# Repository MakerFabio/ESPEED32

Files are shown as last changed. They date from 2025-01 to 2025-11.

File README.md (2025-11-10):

# SlotEsp32
WARNING: the magnetic sensor TLE493D-P3B6 A0 is the version 3 silicon available on Digikey or mouser. Please note the older version (P2) has issues , some other guys have been able to make it working, but I was not.  Please note, the last part (A0) of the part number is related to the address, if you purchase TLE493D-P3B6 A0 it will have 0x5D, A1 it will have 0x13, and so on, please double check the part number you ordered, and the datasheet for the proper address (I think we are using the 7 bit address )

Cutting edge Slot car controller that has an ESP32 at its heart.
How to built it video:
https://www.youtube.com/watch?v=JtMKeiguHKI
ThumbV2

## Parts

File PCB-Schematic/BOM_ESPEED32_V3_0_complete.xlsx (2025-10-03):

Comment | Designator | Footprint
Comment | Designator | Footprint | JLCPCB Part #（optional） | JLC BASIC/EXTENDED | Mounting Option | Quantity | Description
NO_POP_Mill-Max 2501-2-00-80-00-00-07-0 | 5V | TEST POINT MILL-MAX 2501-2-00-80-00-00-07-0 |  |  | DO NOT MOUNT | 1 | testpad 1mm diameter
BUZ9032SMD | BUZ | BUZ9032_SMD |  | BuySeparately |  | 1 | Header, 2-Pin
100nF | C1, C6, C8, C9, C10, C11, C12 | C0603 | C28233 | BASIC |  | 7 | CAP / CERA / 100nF / 25V / 10% / X8R (EIA) / -55°C to 150°C / 0603(1608) / SMD / -
10nF 50V 0603 | C2, C4, C7, C13, C14 | C0603 | C57112 | BASIC |  | 5 | CAPACITOR, European symbol
22uF | C3, C15, C16 | CAPC3225X270N | C13585 | BASIC |  | 3 | CAP / CERA / 22uF / 25V / 20% / X5R (EIA) / -55°C to 85°C / 1210(3225) / SMD / -
1uF | C5 | CAPC1608X87N-1 | C15849 | BASIC |  | 1 | CAP / CERA / 1uF / 25V / 20% / X5R (EIA) / -55°C to 85°C / 0603(1608) / SMD / -
5016 | CAP-, CAP+, GND, VIN+, WIPER | CON-SMD-TP-5016 |  |  | DO NOT MOUNT | 5 | Test Point, Compact, Surface Mount, Finish- Silver Plate
RF05VYM2SFH | D2 | DIO-SMD-RF05VYM2SFH | C509964 |  |  | 1 | Super Fast Recovery Diode
ZENER 10V(MM3Z10VT1G) | DZ3 | SOD323 | C39057 |  |  | 1 | Zener 10V MM3Z10VST1G
PEC11L-4120K-S0020 | ENC1 | SW-THT-PEC11L-4XXXK-SXXXX |  |  | DO NOT MOUNT | 1 | 11 mm Low Profile Encoder
HTSW-103-07-G-S | EXT_MOT, T_POT | CON-THT-2.54-3-1-8.38 |  |  |  | 2 | Through hole .025 SQ Post Header, 2.54mm pitch, 3 pin, vertical, single row
IFX7805ABTF | G1 | TO228P998X235-3N-2-V | C897464 | Extended |  | 1 | Three Terminal 1.0A Positive Voltage Regulator
OLED128x64 MDOB128064V2V-YI | OLED1 | OLED 128X64 1.3" |  |  |  | 1 | Header, 4-Pin
2N7002WT1G | Q1 | SOT65P220X100-3N | C232391 | Extended |  | 1 | Insulated-Gate Field-Effect Transistor (IGFET), N-Channel, Enhancement, Body Diode, Resistor Gate, ESD Diode Gate/Source, Pin 1 Gate, 2 Source, 3 Drain, 3 Pins
IPD90P03P4L-04 | Q2 | TO228P998X235-3N-2-V |  |  |  | 1 | OptiMOS - P2 Power-Transistor, P-channel-Enhancement mode, VDS -30V
0R | R1, R16, R18, R19 | R0603 | C21189 | DOUBLE CHECK |  | 4 | General Purpose Chip Resistor
10k | R2, R9, R10, R11, R12, R13, R15 | R0603 | C25804 | BASIC |  | 7 | RES / STD / 10k / 100mW / 5% / 100ppm/K / -55°C to 155°C / 0603(1608) / SMD / -
2.2k | R3, R6, R7, R8, R14, R20, R21, R22, R23, R24 | R0603 | C4190 | BASIC |  | 10 | RES / STD / 2.2k / 100mW / 1% / 100ppm/K / -55°C to 155°C / 0603(1608) / SMD / -
N.M. 0R | R4, R5 | R0603 |  |  |  | 2 | General Purpose Chip Resistor
PTS645SM43SMTR92 LFS | S1 | SW-SMD-PTS645SK43SMTR92 | C285473 |  |  | 1 | Tact Switches, Variety of Actuator Lengths
HTSW-104-07-G-S | SPARE | HDRV4W64P254_1X4_1016X248X838B |  |  | DO NOT MOUNT | 1 | Through hole .025 SQ Post Header, Hi-Temp Strip, 2.54mm pitch, 4 pin, vertical, single row
ESP32-DEVKIT-V1 | U1 | MODULE_ESP32_DEVKIT_V1 |  |  |  | 1 | Dual core, Wi-Fi: 2.4 GHz up to 150 Mbits/s,BLE (Bluetooth Low Energy) and legacy Bluetooth, 32 bits, Up to 240 MHz
BTN9960LV | U2 | IFX-PG-HSOF-7-1-V |  |  |  | 1 | MOTIX Single Half-Bridge with Integrated Driver IC
TLE493D-W2B6 A3 | U3 | SOP95P280X110-6N-V |  |  |  | 1 | Low Power 3D Hall Sensor with I2C Interface and Wake Up Function, Temp Range(-40 to 125°C)
LEGENDA:(colour code)
Not mounted but Nice to havefrom digik | Extended of Basic | NOT needed /not mounted |  |  |  | I will mount later by myself

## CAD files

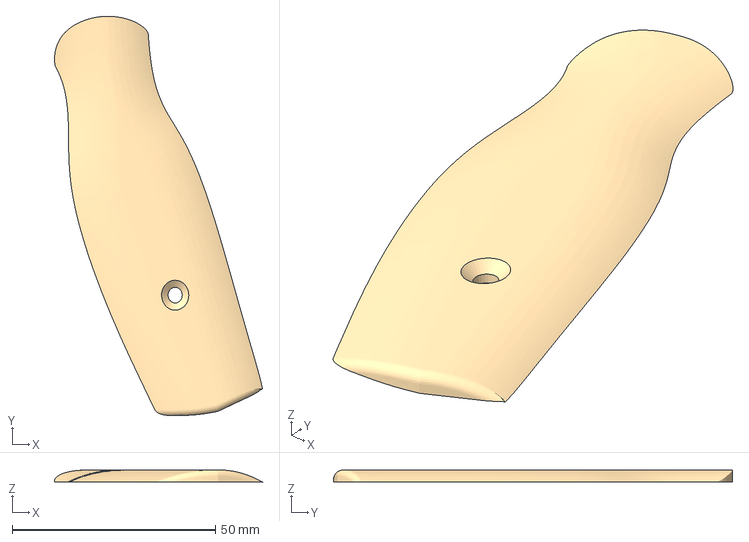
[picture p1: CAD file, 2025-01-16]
Mechanical/3DprintFiles/RoundingTopV47.3mf
51.1 x 98.2 x 3.00 mm

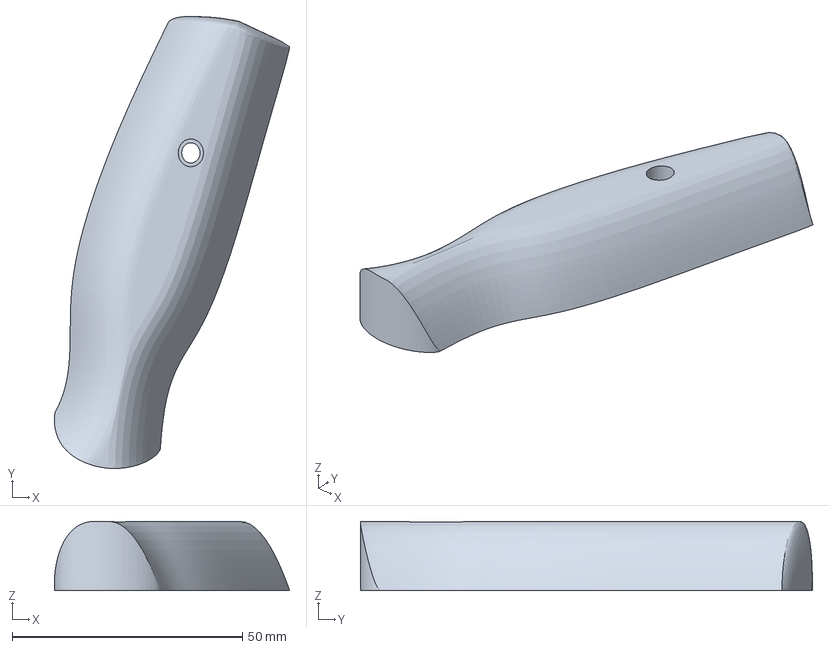
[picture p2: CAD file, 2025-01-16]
Mechanical/3DprintFiles/RoundingBotAddia_15mmV47.3mf
51.1 x 98.2 x 15.0 mm

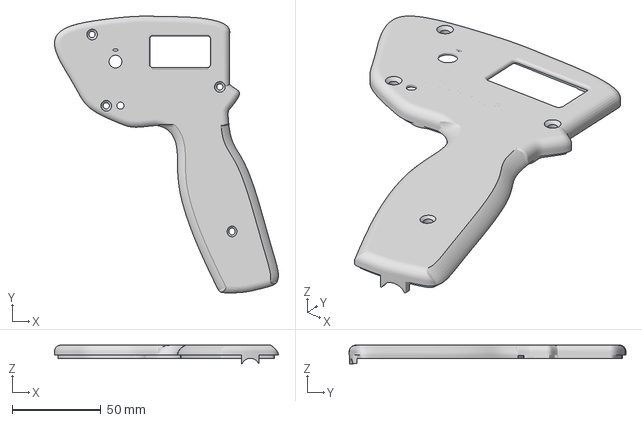
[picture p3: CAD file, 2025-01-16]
Mechanical/3DprintFiles/HandleTopV29.3mf
126.1 x 155.8 x 10.6 mm

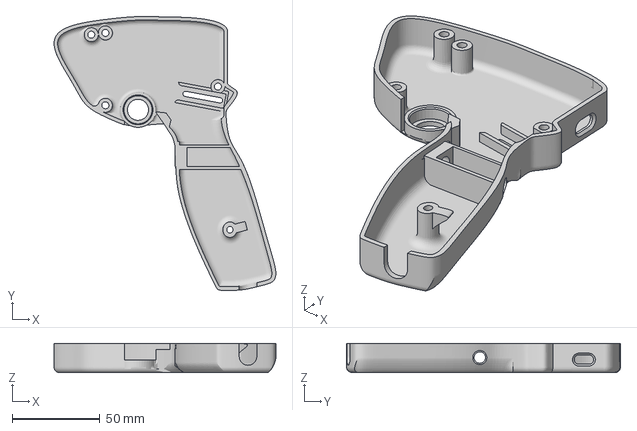
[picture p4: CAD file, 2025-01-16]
Mechanical/3DprintFiles/HandleBotV29.3mf
126.1 x 155.8 x 16.5 mm

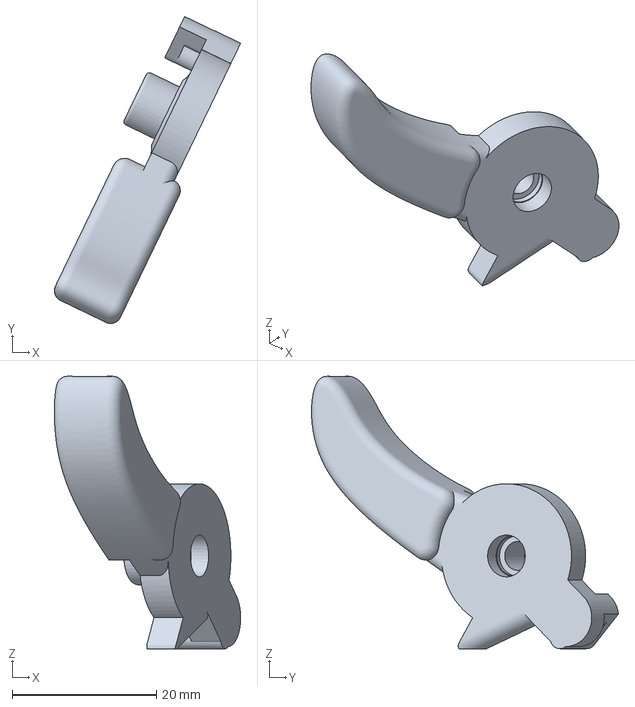
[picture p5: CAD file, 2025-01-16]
Mechanical/3DprintFiles/TrigVeryThick10mm.3mf
25.8 x 42.5 x 37.8 mm

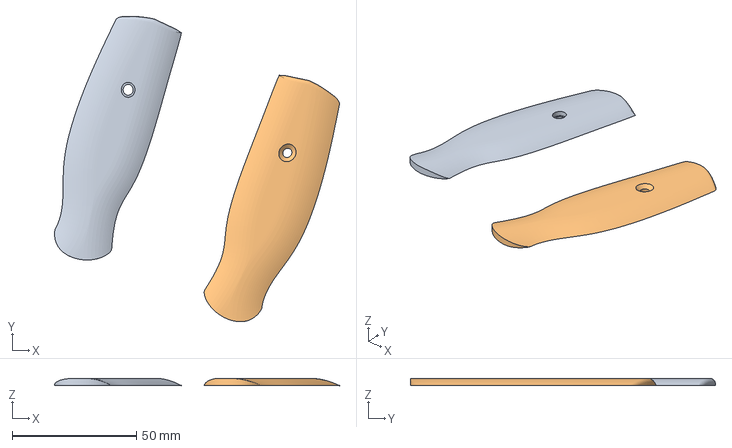
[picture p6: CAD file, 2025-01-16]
Mechanical/3DprintFiles/Rounding2sides.3mf
114.8 x 123.0 x 3.00 mm
RoundingBot
RoundingTop

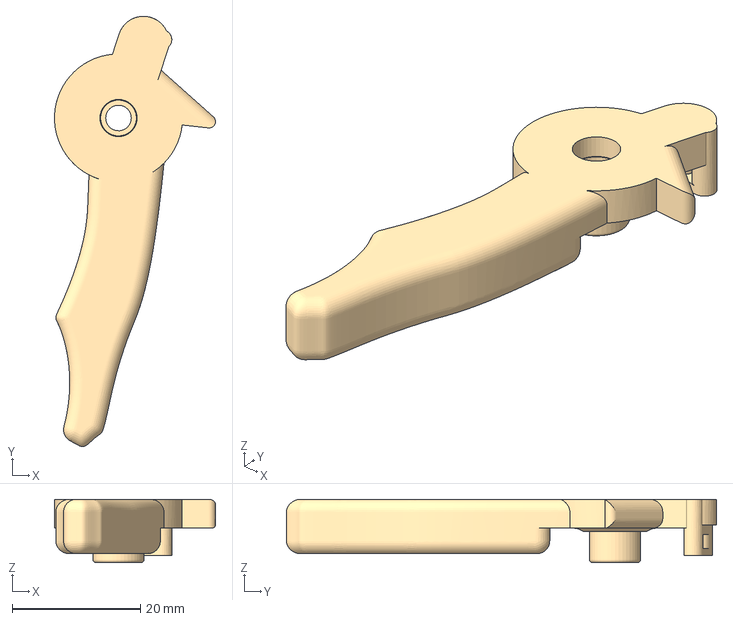
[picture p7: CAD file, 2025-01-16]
Mechanical/3DprintFiles/TrigLongV33.3mf
25.1 x 67.2 x 9.90 mm

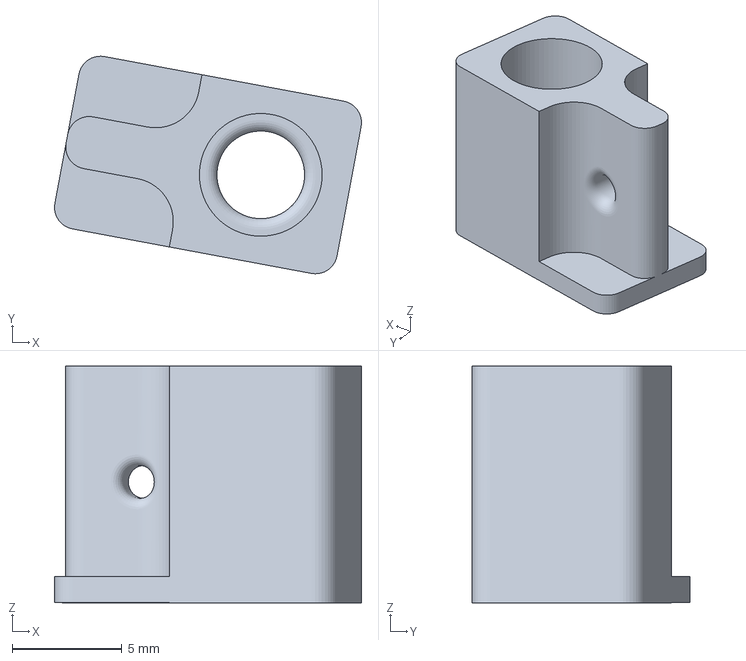
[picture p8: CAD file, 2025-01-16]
Mechanical/3DprintFiles/Slide.3mf
14.0 x 9.93 x 10.8 mm

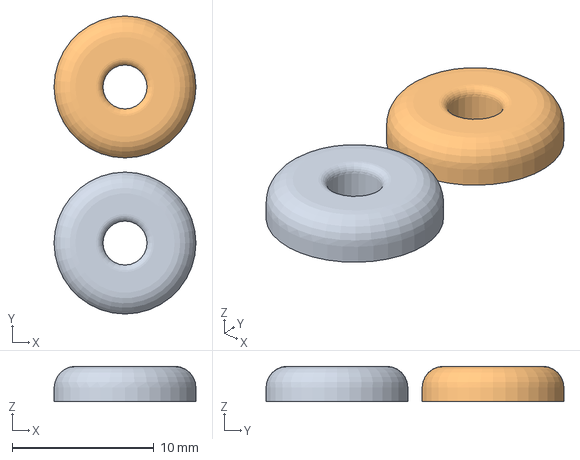
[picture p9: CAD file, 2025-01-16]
Mechanical/3DprintFiles/WasherOnly.3mf
10.0 x 21.0 x 2.50 mm
Washer x 2

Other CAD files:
Mechanical/3DprintFiles/RoundingBotv47.3mf

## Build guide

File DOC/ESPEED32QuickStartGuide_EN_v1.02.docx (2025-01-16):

# ESPEED32 Slot Car Electronic Speed Controller

Quick Start Guide

EN

## Introduction

The ESPEED32 is a powerful Slot Car Electronic Speed Controller based on the 32-bit ESP32 microcontroller.

## Calibration

The calibration of the trigger travel must be performed every time the trigger travel is changed, or the firmware is updated. To perform the trigger calibration, keep pressed the rotary selector while powering the ESPEED32, until the calibration screen appears. Fully press and release the trigger a few times, then press the rotary selector once. To verify a proper calibration, check if the throttle is showing 0% when the trigger is fully released, and 100% when the trigger is fully pressed.

## Navigating the screen

Rotate the rotary selector to scroll the settings in the main menu: the selected setting is highlighted. Press the selector once to change the value of the selected setting: the value is now highlighted. Rotate the selector to change the value of the selected setting, then press the selector again to confirm the value.

## Settings

SENSI – Sensitivity: Indicates the power provided to the motor when the minimum detectable pressure is applied to the trigger. The sensitivity should be at least sufficient for the car to start moving. If the track is “fast” or the car is “heavy”, then a higher sensitivity can be chosen. SENSI measurement unit is percent [%] and ranges from 0% to 90%.

BRAKE – Brake level: Indicates how strong the motor will brake when the trigger is completely released. In order to perform the brake, the motor is shorted with a PWM whose duty cycle is equal to the value of BRAKE. BRAKE measurement unit is percent [%] and ranges from 0% to 100% (100% means max brake is applied).

ANTIS – Anti-spin: Anti-spin (traction control) is used to provide a smooth power ramp to the motor, even if the trigger is pressed abruptly. ANTIS is expressed in milliseconds [ms]. It indicates how much time it takes for the motor to reach 100% power with the trigger fully pressed. If ANTIS is set to 150 ms and the trigger is pressed instantaneously, then the motor will receive a power ramp that will take 150ms to reach the max power. The higher the number the softer is the power ramp applied. ANTIS possible value ranges from 0 ms to 250 ms.

Typical ANTIS value: 130 ms for 1/32 cars; 0 ms for 1/24 cars

CURVE – Trigger-to-motor power curve: the CURVE parameter allows to customize the mapping of the trigger position to the motor power output. A default value of 50% corresponds to a linear curve. If CURVE is <50% the response of the trigger will be softer at the beginning of the travel and more aggressive at the end; vice versa if CURVE is >50%. Ranges from 10% to 90%.

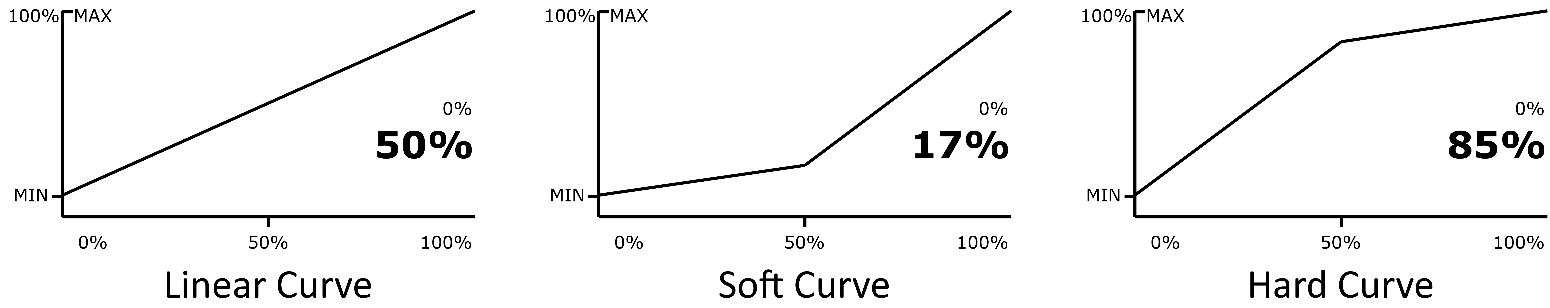
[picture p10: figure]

Figure 1 CURVE setting examples.

PWM_F – motor PWM frequency: the frequency of the PWM (Pulse Width Modulation) used to control the motor. A higher frequency produces a softer response, especially at low trigger positions; a lower frequency produces higher torque with minimum throttle and more linear response. PWM_F measurements unit is Kilohertz [kHz] and ranges from 0.2kHz to 5.0kHz

Table 1 Settings overview

Setting | Recommended value | Range | | Unit
| | Min. | Max.
SENSI | 10 | 0 | 90 | %
BRAKE | 95 | 0 | 100 | %
ANTIS | 150 for 1/32 cars 0 for 1/24 cars | 0 | 255 | ms
CURVE | 50 | 10 | 90 | %
DRAGB | 100 | 0 | 100 | %
PWM_F | 3 | 0.2 | 5.0 | kHz

## Electrical Specifications - recommended operating condition

Setting | Symbol | Value | | | Unit
| | Min. | Typ. | Max.
Power supply voltage | VIN+ | 6.0 | 12 | 18 | V
Motor Current | I_(VDD) | 35 | 47 | 60 | mA
Startup Time | t_(startUp) | - | 150 | - | ms

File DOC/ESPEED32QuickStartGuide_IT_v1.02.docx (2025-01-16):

# ESPEED32 Quick Start Guide

Guida rapida

IT

## Introduzione

L’ ESPEED32 è un pulsante professionale per slot car basato sul microcontrollore ESP32 a 32 bit.

## Calibrazione

La calibrazione del grilletto deve essere eseguita ogni volta che si modifica la corsa del grilletto o si aggiorna il firmware. Per eseguire la calibrazione del grilletto, mantenere premuto il selettore rotativo mentre si alimenta l’ ESPEED32, finché non appare la schermata di calibrazione. A questo punto rilasciate il pulsante sul selettore rotativo. La calibrazione consiste nel premere e rilasciare completamente il grilletto 2-3 volte, quindi premere nuovamente volta il selettore rotativo per uscire e salvare la calibrazione. Per verificare che la calibrazione sia corretta, controllare se l’indicatore dell’acceleratore mostra 0% quando il grilletto è completamente rilasciato e 100% quando il grilletto è completamente premuto.

## Navigazione sullo schermo

Ruotare il selettore rotativo per scorrere le impostazioni nel menu principale: l'impostazione selezionata è evidenziata. Premere una volta il selettore per modificare il valore dell'impostazione selezionata: il valore è ora evidenziato. Ruotare il selettore per modificare il valore dell'impostazione selezionata, quindi premere nuovamente il selettore per confermare il valore.

## Impostazioni

SENSI – Sensibilità: Indica la potenza minima fornita al motore. E’ la potenza che viene applicata al motore alla minima pressione rilevabile al grilletto. La sensibilità dovrebbe essere almeno sufficiente per far partire l'auto. Se il percorso è "veloce" o l'auto è poco sensibile, è possibile scegliere una sensibilità (SENSI) maggiore, anche il 50% per esempio. L'unità di misura SENSI è percentuale [%] e varia da 0% a 90%.

BRAKE – Livello freno: Indica la potenza di frenata del motore quando il grilletto viene completamente rilasciato. Per eseguire la frenata, il motore viene messo in cortocircuito con un PWM il cui ciclo di lavoro è uguale al valore di BRAKE. L'unità di misura BRAKE è percentuale [%] e varia da 0% a 100% (100% significa che è applicata la massima frenata).

ANTIS – Antispin: Antispin (controllo della trazione)

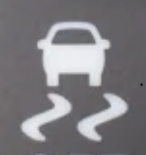
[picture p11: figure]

L’antispin viene utilizzato per fornire una rampa graduale di potenza al motore, anche se il grilletto viene premuto bruscamente. Questo previene lo slittamento della macchina. ANTIS è espresso in millisecondi [ms]. Indica quanto tempo impiega il motore a per andare da 0% al 100% di potenza quando il grilletto viene premulto bruscamente.Ad esempio, ANTIS= 150ms e il grilletto viene premuto istantaneamente, il motore riceverà una rampa di potenza che impiegherà 150 ms per raggiungere la potenza massima. Più alto è il numero sul parametero ANITS, più morbida è la rampa di potenza applicata. I valori possibili di ANTIS vanno da 0 ms a 250 ms. Valore ANTIS tipico: 130 ms per auto 1/32; 0 ms per auto 1/24


CURVE –Curva posizione trigger/potenza motore. il parametro CURVE consente di personalizzare la mappatura della posizione del trigger in base alla potenza in uscita dal motore. Un valore predefinito del 50% corrisponde a una curva lineare. Se CURVE è <50% la risposta del trigger sarà più morbida all'inizio della corsa e più aggressiva alla fine; viceversa seCURVE è >50%. Varia dal 10% al 90%.

PWM_F – frequenza PWM del motore: la frequenza del PWM (Pulse Width Modulation) utilizzato per controllare il motore. Una frequenza più alta produce una risposta più morbida, specialmente a basse posizioni di trigger; una frequenza più bassa produce una coppia più alta con accelerazione minima e una risposta più lineare. L'unità di misura PWM_F è Kilohertz [kHz] e varia da 0,2kHz a 5,0kHz

Parametro | Valore consigliato | Range | Unità di misura
SENSI | 10% | 0% - 90% | Percentuale [%]
BRAKE | 90% | 0% - 100% | Percentuale [%]
ANTIS | 130 ms per 1/32, 0 ms per 1/24 | 0 - 250 ms | Millisecondi [ms]
CURVE | 50% | 10% - 90% | Percentuale [%]
DRAGB | 100% | 0% - 100% | Percentuale [%]
PWM_F | 3 kHz | 0,2 - 5,0kHz | Chilohertz [kHz]

## Electrical Characteristics (recommended operating condition)

Setting | Symbol | Value | | | Unit
| | Min. | Typ. | Max.
Power supply voltage | VIN+ | 6.0 | 12 | 18 | V
Motor Current | I_(VDD) | 35 | 47 | 60 | mA
Startup Time | t_(startUp) | - | 150 | - | ms

ESPEED32|Quick Start Guide

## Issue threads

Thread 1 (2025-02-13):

parts

FTSSMike, 2025-02-13:
has anyone found the Infineon part out there somewhere or is there anther part that can be used. Also looks like one part is discontinued does anyone have a part number to replace it?  thank you

TurboMikeFTS, 2025-02-21:
I found everything but the hall sensor if anyone sees one please post up

Hcbo1967, 2025-02-22:
I'd like to help improve this. Can you send me all the files including Gerber files of the PCB?
Hamilton
thank you

fehcbo@yahoo.com

TurboMikeFTS, 2025-02-22:
I will when i get to my office

jeppojeps, 2025-03-09:
@MakerFabio would this work

726-TLE493DW2B6A3HTS
https://www.mouser.es/ProductDetail/Infineon-Technologies/TLE493DW2B6A3HTSA1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

TurboMikeFTS, 2025-03-09:
I have a couple on order to try, read the comments on you tube someone got it to work but some code was changed

jeppojeps, 2025-03-22:
I believe finally it's available

https://www.digikey.es/en/products/detail/infineon-technologies/TLE493DP3B6A0HTSA1/25902161

@MakerFabio is the correct one no?

MakerFabio, 2025-03-23:
yes, it is finally available
the part you pointed is correct

FTSSMike, 2025-04-07:
The correct hall sensor just showed up in one of the online stores  https://www.rutronik24.com/product/infineon/tle493dp3b6a0htsa1/24620689.html they show 150 units

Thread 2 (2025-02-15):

polarity change

rufusms, 2025-02-15:
Hello, I found this controller, which I think is fantastic and I started to build it based on the schematics and using a perfboard, I found another half bridge, BTS7960, which is similar and I assembled the circuit, the controller I used is an old NINCO, transformed to work as a potentiometer and I added a declaration in the program, so that it works, the problem I find now is that my track uses the positive instead of the negative , then it works off-piste but not on it.

rufusms, 2025-02-21:
Hello again, I have finally finished building this controller, to use it I had to change the polarity of the track, in general it works very well but I observe that when I put curves with a lower value than 80%, the voltage value does not reach 100%, from 68% it becomes very unstable, I have verified that the noise level at the signal input is very low, of the order of 2% at most, and the stability of the signal is 100%, I thought that since my sensor input is resistive instead of magnetic, it would have more noise and instability but that is not the case, perhaps it is that the acquisition is through an analog input instead of I2C.

TurboMikeFTS, 2025-02-21:
That should be fixable. I’m waiting on some parts and I’ll finish a couple.

Hcbo1967, 2025-02-22:
I'd like to help improve this. Can you send me all the files including Gerber files of the PCB?
Hamilton
thank you

fehcbo@yahoo.com

Hcbo1967, 2025-02-28:
> Olá, encontrei este controlador, que acho fantástico e comecei a montá-lo com base nos esquemas e usando uma perfboard, encontrei outra meia ponte, BTS7960, que é semelhante e montei o circuito, o controlador que usei é um NINCO antigo, transformado para funcionar como um potenciômetro e adicionei uma declaração no programa, para que funcione, o problema que encontro agora é que minha pista usa o positivo em vez do negativo, então funciona fora de pista, mas não nela.

> Olá, encontrei este controlador, que acho fantástico e comecei a montá-lo com base nos esquemas e usando uma perfboard, encontrei outra meia ponte, BTS7960, que é semelhante e montei o circuito, o controlador que usei é um NINCO antigo, transformado para funcionar como um potenciômetro e adicionei uma declaração no programa, para que funcione, o problema que encontro agora é que minha pista usa o positivo em vez do negativo, então funciona fora de pista,

> Olá novamente, finalmente terminei de construir este controlador, para usá-lo tive que mudar a polaridade da trilha, em geral funciona muito bem, mas observo que quando coloco curvas com valor menor que 80%, o valor da tensão não chega a 100%, a partir de 68% fica muito instável, verifiquei que o nível de ruído na entrada do sinal é muito baixo, da ordem de 2% no máximo, e a estabilidade do sinal é de 100%, pensei que como minha entrada de sensor é resistiva em vez de magnética, teria mais ruído e instabilidade, mas não é o caso, talvez seja que a aquisição seja por uma entrada analógica em vez de I2C.

I'm interested in making changes and sharing them here with other users. Can you send me the complete file with all the files for my e-mail?
fehcbo@yahoo.com

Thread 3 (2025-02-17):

BOM missing from repository

one4worldpeace, 2025-02-17:
the Bill of materials was in the file list
and then was replaced with what looked like a record of expenses
and is now not to be found.

the loading screen says “press button” is this referring to the small red button ommitted in your video?

TurboMikeFTS, 2025-02-18:
I can send you my download, send your email

Hcbo1967, 2025-02-22:
I'd like to help improve this. Can you send me all the files including Gerber files of the PCB?
Hamilton
thank you

fehcbo@yahoo.com

TurboMikeFTS, 2025-02-22:
i will send it monday i have the complete zip at my office

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

Hcbo1967, 2025-02-23:
ok
Thanks

one4worldpeace, 2025-02-23:
***@***.*** thank you kindly

On Tue, Feb 18, 2025 at 12:22 PM TurboMikeFTS ***@***.***>
wrote:

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

m4n-u, 2025-08-31:
hell my friend do u have a link to get gerber  file? and  parts list?, thanks

m4n-u, 2025-08-31:
> I can send you my download, send your email

Hello friend how are you, i ve been trying to get all the files to make the controller for my own but i cant find BOM, Gerber, part list, etc, i just read that maybe u have the files, it is posible that you share with me? thanks  manuel.galvez.@live.com

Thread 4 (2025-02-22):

software wont verify

TurboMikeFTS, 2025-02-22:
did anyone get the software to compile properly? I am trying to program the esp32

Hcbo1967, 2025-02-23:
Have you the files Gerber of PCB?
I can help you resolve this.
The Gerber files are currently not available for download.
Please, send me all files fory e-mail.
fehcbo@yahoo.com

Hamilton

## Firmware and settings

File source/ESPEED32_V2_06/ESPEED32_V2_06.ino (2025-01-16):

/*********************************************************************************************************************/
/*------------------------------------------------------Includes-----------------------------------------------------*/
/*********************************************************************************************************************/
#include "slot_ESC.h"

/*********************************************************************************************************************/
/*-------------------------------------------------------Macros------------------------------------------------------*/
/*********************************************************************************************************************/
#define BOOTLOADER_BUILD 1
//#define LOG_LOCAL_LEVEL ESP_LOG_NONE
#define CONFIG_BOOTLOADER_LOG_LEVEL ESP_LOG_NONE

#define SW_MAJOR_VERSION 2
#define SW_MINOR_VERSION 06
#define STORED_VAR_VERSION 4 /* tells which version of stored variable is used for thisproject in case the stored var */
                             /* changes from previous SW release, please increase the STORED_VAR_VERSION by 1         */

/* Last modified: 17/10/2024 */
/*********************************************************************************************************************/
/*-------------------------------------------------Global variables--------------------------------------------------*/
/*********************************************************************************************************************/

//CONFIG_BOOTLOADER_SKIP_VALIDATE_ON_POWER_ON=y not existing
//CONFIG_BOOTLOADER_SKIP_VALIDATE_IN_DEEP_SLEEP


TaskHandle_t Task1;
TaskHandle_t Task2;

static StateMachine_enum g_currState = INIT;
uint16_t debug;

/* Display Backbuffer */
#ifdef USE_BACKBUFFER
static uint8_t ucBackBuffer[1024];
#else
static uint8_t *ucBackBuffer = NULL;
#endif

OBDISP g_obd;       /* Display global instance */

char msgStr[50];    /* Display string global instance */


uint16_t g_carSel;  /* global variable telling whch car model has been selected */

/* Rotary Encoder global instance */
AiEsp32RotaryEncoder g_rotaryEncoder = AiEsp32RotaryEncoder(ENCODER_A_PIN, ENCODER_B_PIN, ENCODER_BUTTON_PIN, ENCODER_VCC_PIN, ENCODER_STEPS);

static uint8_t g_encoderMainSelector = 1;           /* Value of main menu selector (indicates selected item) */
static uint8_t g_encoderSecondarySelector = 0;      /* Value of secondarty selector (indicates selected item's value) */
static uint16_t *g_encoderSelectedValuePtr = NULL;  /* Global instance of pointer to the value selected by the encoder */


/* EEPROM stored values (mainly calibration) global instance */
StoredVar_type g_storedVar;

/* ESC internal variables gloabl instance */
ESC_type g_escVar{
  .outputSpeed_pct = 0,
  .trigger_raw = 0,
  .trigger_norm = 0,
  .encoderPos = 1,
  .Vin_mV = 0,
  .dualCurve = false
};

/* Main menu global instances */
Menu_type g_mainMenu{
  .lines = 3
};

/* Car menu global instances */
Menu_type g_carMenu{
  .lines = 3
};

/* Preferences global instance (for storing NVM data, replace EEPROM library) */
Preferences g_pref;

static uint32_t g_lastEncoderInteraction = 0;  /* tell how much time has passed since last time encoder whas rotated/pressed
                                                  so we can avoid keep printing the display menu and save CPU cycles */

/*********************************************************************************************************************/
/*--------------------------------------------- Function Declaration----------------------------------------*/
/*********************************************************************************************************************/
void IRAM_ATTR readEncoderISR();


/*********************************************************************************************************************/
/*---------------------------------------------Setup Function Implementations----------------------------------------*/
/*********************************************************************************************************************/

/* Setup */
void setup()
{

  /***** Pin and Serial Setup *****/
  HAL_PinSetup();

  /***** HalfBridge & HW Setup *****/
  HalfBridge_SetupFabio();

  /***** create a task that will be executed in the Task1code() and Task2code() funcitons, executed on core 0 and 1 *****/
  /* TASK1: slotESC state machine, managex OLED display and Encoder, low priority task */
  xTaskCreatePinnedToCore(
    Task1code, /* Task function. */
    "Task1",   /* name of task. */
    10000,     /* Stack size of task */
    NULL,      /* parameter of the task */
    1,         /* priority of the task */
    &Task1,    /* Task handle to keep track of created task */
    0);        /* pin task to core 0 */
  /* TASK2: perform trigger reading, trigger conditioning, PWM output */
  xTaskCreatePinnedToCore(
    Task2code, /* Task function. */
    "Task2",   /* name of task. */
    10000,     /* Stack size of task */
    NULL,      /* parameter of the task */
    2,         /* priority of the task */
    &Task2,    /* Task handle to keep track of created task */
    1);        /* pin task to core 1 */
}


/*********************************************************************************************************************/
/*---------------------------------------------MAIN LOOP IN TASKS----------------------------------------------*/
/*********************************************************************************************************************/

/**
 * Task 1: slotESC state machine: manage OLED display and Encoder, low priority task
 */
void Task1code(void *pvParameters) 
{
  for (;;) 
  {
    StateMachine_enum prevState = g_currState;  /* Keep track of the state at the previous loop */
    static uint16_t prevFreqPWM = 0;            /* Keep track if the PWM freq has changed */
    static MenuState_enum menuState = ITEM_SELECTION;   /* State of the Main Menu */
    static uint8_t swMajVer, swMinVer, storedVarVersion;/* SW major version, minor version,  storedVariable version stored in the eeprom */

    g_escVar.Vin_mV = HAL_ReadVoltageDivider(AN_VIN_DIV, RVIFBL, RVIFBH); /* Read VIN */

    if (g_currState != INIT) /* If the user params are already fetched from the EEPROM */
      {
        g_carSel = g_storedVar.selectedCarNumber;    /* Update global variable telling which car model is actually selected */
      }

    /* Task 1 state machine */
    switch (g_currState) {
      case INIT:

        g_pref.begin("stored_var", false); /* Open the "stored" namespace in read/write mode. If it doesn't exist, it creates it */
        
        if (g_pref.isKey("stored_var_ver") && g_pref.isKey("sw_maj_ver") && g_pref.isKey("sw_min_ver") && g_pref.isKey("user_param")) /* If all keys exists, then check their value */
        {
          /* Get the values of the sw version */
          swMajVer = g_pref.getUChar("sw_maj_ver");
          swMinVer = g_pref.getUChar("sw_min_ver");
          storedVarVersion = g_pref.getUChar("stored_var_ver");

          if ((storedVarVersion == STORED_VAR_VERSION) ) /* If the storedVariable version keys is equal to the STORED_VAR MACRO, then the stored param are already initialized woh the proper format*/
          {
            g_pref.getBytes("user_param", &g_storedVar, sizeof(g_storedVar)); /* Get the value of the stored user_param */
            initMenuItems();                                                  /* init menu items with EEPROM stored variables */

            /* If button is pressed at startup, go to CALIBRATION state */
            if (digitalRead(ENCODER_BUTTON_PIN) == BUTTON_PRESSED) 
            {
              g_currState = CALIBRATION;      /* Go to CALIBRATION state */
              /* Reset Min and Max to the opposite side, in order to have effective calibration */
              g_storedVar.minTrigger_raw = MAX_INT16;
              g_storedVar.maxTrigger_raw = MIN_INT16;
              calibSound();             /* Play calibration sound */
              initDisplayAndEncoder();  /* init and clear OLED and Encoder */

              /* Wait until button is released, then go to CALIBRATION state */
              while (digitalRead(ENCODER_BUTTON_PIN) == BUTTON_PRESSED)
              {
                showScreenPreCalibration();
              }
              
              obdFill(&g_obd, OBD_WHITE, 1); /* Clear OLED */
            }
            else  /* If button is NOT pressed at startup, go to RUNNING state */
            {
              g_currState = WELCOME;                    /* Go to WELCOME state */
              g_carSel = g_storedVar.selectedCarNumber; /* now it is safe to address the proper car */
              initDisplayAndEncoder();  /* init and clear OLED and Encoder */
              onSound();                /* Play ON sound */
            }

            g_pref.end(); /* Close the namespace */
            break;        /* Break the switch case: if code reaches here, it means that the stored user param and sw versions are OK */
          }
        }

        /* If the code reaches here it means that:
        - the sw version keys are not present --> stored var are not initialized
        - the sw version stored are not up to date --> stored var are initialized but might be outdated

        Calibration values are NOT stored, go to CALIBRATION state */
        initDisplayAndEncoder();  /* init and clear OLED and Encoder */
                              
        g_pref.clear();           /* Clear all the keys in this namespace */
        /* Store the correct SW version */
        g_pref.putUChar("sw_maj_ver", SW_MAJOR_VERSION);
        g_pref.putUChar("sw_min_ver", SW_MINOR_VERSION);
        
        g_pref.putUChar("stored_var_ver", STORED_VAR_VERSION);

        initStoredVariables();  /* Initialize stored variables with default values */

        /* Reset Min and Max to the opposite side, in order to have effective calibration */
        g_storedVar.minTrigger_raw = MAX_INT16;
        g_storedVar.maxTrigger_raw = MIN_INT16;
        calibSound();                   /* Play calibration sound */
        g_currState = CALIBRATION;      /* Go to CALIBRATION state */
        obdFill(&g_obd, OBD_WHITE, 1); /* Clear OLED */
        /* Press and release button to go to CALIBRATION state */
        while (!g_rotaryEncoder.isEncoderButtonClicked()) /* Loop until button is pressed */
        {
          showScreenNoEEPROM();
        }

        break;


      case CALIBRATION:
        /* Read Throttle */
        throttleCalibration(g_escVar.trigger_raw);    /* trigger raw is continuously read on task2 */
        showScreenCalibration(g_escVar.trigger_raw);  /* Show calibration screen */
        /* Exit calibration if button is presseded */
        if (g_rotaryEncoder.isEncoderButtonClicked())  /* exit calibration and save calibration data to EEPROM */
        {
          offSound();
          initMenuItems();  /* Init Menu Items */
          saveEEPROM(g_storedVar);  /* Save modified calibration values to EEPROM */
          HalfBridge_Enable();    /* Enable HalfBridge */
          g_currState = WELCOME;  /* Go to WELCOME state */
        }
        break;


      case WELCOME:
        /* This WELCOME state is only used to show the SW versions on the Screen, but the controller is actually fully operational:
            - Calibration is OKAY (either just done, or using stored values)
            - User param are OKAY (either just initialized to default, or using stored values)
            - Trigger is being read on Task 2

          The user trigger input is being elaborated and the correct speed (PWM) output is being produced for the whole duration of the WELCOME state */

        showScreenWelcome();    /* Show welcome screen */
        delay(1500);            /* Wait one second */
        g_currState = RUNNING;  /* Go to RUNNING state */
        break;


      case RUNNING: /* when the global variable State is in RUNNING the Task2 will elaborate the trigger to produce the PWM out */

        /* Change menu state if encoder button is clicked */
        if (g_rotaryEncoder.isEncoderButtonClicked()) 
        {
          menuState = rotary_onButtonClick(menuState);  /* This function is called if the encoder is pressed
                                                           Take the current menu state and returns the next menu state */
          g_lastEncoderInteraction = millis();          /* Update last encoder interaction */
        }

        /* Get encoder position if it was changed*/
        if (g_rotaryEncoder.encoderChanged()) 
        {
          g_escVar.encoderPos = g_rotaryEncoder.readEncoder();  /* Update the global ESC variable keeping track of the encoder value (position) */
          g_lastEncoderInteraction = millis();  /* Update last encoder interaction */
        }
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
void loop() {}

/*********************************************************************************************************************/
/*---------------------------------------------Setup Function Implementations----------------------------------------------*/
/*********************************************************************************************************************/

/*
  Initialize OLED display and encoder.
  This is done separately from the HW init to shorten the startup time.
*/
void initDisplayAndEncoder() 
{
  uint16_t rc;
  /***** OLED Display Setup *****/
  rc = obdI2CInit(&g_obd, MY_OLED, OLED_ADDR, FLIP180, INVERT_DISP, USE_HW_I2C, SDA1_PIN, SCL1_PIN, RESET_PIN, 800000L);  // use standard I2C bus at 400Khz
  if (rc != OLED_NOT_FOUND) 
  {
    obdSetBackBuffer(&g_obd, ucBackBuffer);
    obdFill(&g_obd, OBD_WHITE, 1);
  } 
  else 
  {
    Serial.println("Error! Failed OLED Display initialization!");
  }

  /***** Encoder Setup *****/
  g_rotaryEncoder.begin();
  g_rotaryEncoder.setup(readEncoderISR);
  g_rotaryEncoder.setBoundaries(1, MENU_ITEMS_COUNT, false); /* minValue, maxValue, circleValues true|false (when max go to min and vice versa) */
  g_rotaryEncoder.setAcceleration(MENU_ACCELERATION);        /* Larger number = more accelearation; 0 or 1 means disabled acceleration */
}


/* Rotary Encoder ISR */
void IRAM_ATTR readEncoderISR() {
  g_rotaryEncoder.readEncoder_ISR();
}


/**
 * Initialize the stored variables with default values.
   This is done for every CAR in the CarParam array.
 */
void initStoredVariables() {
  for (int i = 0; i < CAR_MAX_COUNT; i++) {
    g_storedVar.carParam[i].minSpeed = MIN_SPEED_DEFAULT;
    g_storedVar.carParam[i].brake = BRAKE_DEFAULT;
    g_storedVar.carParam[i].dragBrake = DRAG_BRAKE_DEFAULT;
    g_storedVar.carParam[i].maxSpeed = MAX_SPEED_DEFAULT;
    g_storedVar.carParam[i].throttleCurveVertex = { THROTTLE_CURVE_INPUT_THROTTLE_DEFAULT, THROTTLE_CURVE_SPEED_DIFF_DEFAULT };
    g_storedVar.carParam[i].antiSpin = ANTISPIN_DEFAULT;
    g_storedVar.carParam[i].freqPWM = PWM_FREQ_DEFAULT;
    g_storedVar.carParam[i].carNumber = i;
    sprintf(g_storedVar.carParam[i].carName, "CAR%1d", i);
  }
  g_storedVar.selectedCarNumber = 0;
  g_storedVar.minTrigger_raw = 0;
  g_storedVar.maxTrigger_raw = ACD_RESOLUTION_STEPS;
}


/**
 * Initialize the menu items with the value from the stored variables.
   Insert the items one by one in the main menu global instance.
   Then insert the items (cars) in the car menu.
   To add an item:
    - update the value of MENU_ITEMS_COUNT to match the amount of items in the menu.
    - update MAX_ITEMS so that it is greater or equal MENU_ITEMS_COUNT.
    - Add the item here, in the desired position (check the comment in slot_ESC.h MenuItem_type to know more).
 */
void initMenuItems() {
  int i = 0;
  /* Init menu items */

  sprintf(g_mainMenu.item[i].name, "BRAKE");
  g_mainMenu.item[i].value = (void *)&g_storedVar.carParam[g_carSel].brake;
  g_mainMenu.item[i].type = VALUE_TYPE_INTEGER;
  g_mainMenu.item[i].unit = '%';
  g_mainMenu.item[i].maxValue = BRAKE_MAX_VALUE;
  g_mainMenu.item[i].minValue = 0;
  g_mainMenu.item[i].callback = ITEM_NO_CALLBACK;

  sprintf(g_mainMenu.item[++i].name, "SENSI");
  g_mainMenu.item[i].value = (void *)&g_storedVar.carParam[g_carSel].minSpeed;
  g_mainMenu.item[i].type = VALUE_TYPE_INTEGER;
  g_mainMenu.item[i].unit = '%';
  g_mainMenu.item[i].maxValue = min(MIN_SPEED_MAX_VALUE, (int)g_storedVar.carParam[g_carSel].maxSpeed);
  g_mainMenu.item[i].minValue = 0;
  g_mainMenu.item[i].callback = ITEM_NO_CALLBACK;

  sprintf(g_mainMenu.item[++i].name, "ANTIS");
  g_mainMenu.item[i].value = (void *)&g_storedVar.carParam[g_carSel].antiSpin;
  g_mainMenu.item[i].type = VALUE_TYPE_INTEGER;
  g_mainMenu.item[i].unit = 'm';
  g_mainMenu.item[i].maxValue = ANTISPIN_MAX_VALUE;
  g_mainMenu.item[i].minValue = 0;
  g_mainMenu.item[i].callback = ITEM_NO_CALLBACK;

  sprintf(g_mainMenu.item[++i].name, "CURVE");
  g_mainMenu.item[i].value = (void *)&g_storedVar.carParam[g_carSel].throttleCurveVertex.curveSpeedDiff;
  g_mainMenu.item[i].type = VALUE_TYPE_INTEGER;
  g_mainMenu.item[i].unit = '%';
  g_mainMenu.item[i].maxValue = THROTTLE_CURVE_SPEED_DIFF_MAX_VALUE;
  g_mainMenu.item[i].minValue = THROTTLE_CURVE_SPEED_DIFF_MIN_VALUE;
  g_mainMenu.item[i].callback = &showCurveSelection;

  sprintf(g_mainMenu.item[++i].name, "PWM_F");
  g_mainMenu.item[i].value = (void *)&g_storedVar.carParam[g_carSel].freqPWM;
  g_mainMenu.item[i].type = VALUE_TYPE_DECIMAL;
  g_mainMenu.item[i].unit = 'k';
  g_mainMenu.item[i].maxValue = FREQ_MAX_VALUE / 100;
  g_mainMenu.item[i].minValue = FREQ_MIN_VALUE / 100;
  g_mainMenu.item[i].decimalPoint = 1;
  g_mainMenu.item[i].callback = ITEM_NO_CALLBACK;

  sprintf(g_mainMenu.item[++i].name, "LIMIT");
  g_mainMenu.item[i].value = (void *)&g_storedVar.carParam[g_carSel].maxSpeed;
  g_mainMenu.item[i].type = VALUE_TYPE_INTEGER;
  g_mainMenu.item[i].unit = '%';
  g_mainMenu.item[i].maxValue = MAX_SPEED_DEFAULT;
  g_mainMenu.item[i].minValue = max(5, (int)g_storedVar.carParam[g_carSel].minSpeed + 5);
  g_mainMenu.item[i].callback = ITEM_NO_CALLBACK;

  sprintf(g_mainMenu.item[++i].name, "*CAR*");
  g_mainMenu.item[i].value = (void *)&g_storedVar.carParam[g_carSel].carName;
  g_mainMenu.item[i].type = VALUE_TYPE_STRING;
  g_mainMenu.item[i].maxValue = CAR_MAX_COUNT - 1;  // so menu will scroll in the array (CAR_MAX_COUNT long)
  g_mainMenu.item[i].minValue = 0;
  g_mainMenu.item[i].callback = &showSelectRenameCar;

  /* Init Car selection menu items */
  for (uint8_t j = 0; j < CAR_MAX_COUNT; j++)
  {
    sprintf(g_carMenu.item[j].name, (const char *)g_storedVar.carParam[j].carName);
    g_carMenu.item[j].value = (void *)&g_storedVar.carParam[j].carNumber;
  }
}


/**
 * Show the Welcome screen
 */
void showScreenWelcome() 
{
  obdWriteString(&g_obd, 0, 16, 12, (char *)"ESPEED32", FONT_12x16, OBD_BLACK, 1);
  obdWriteString(&g_obd, 0, 16, 28, (char *)"BRM", FONT_12x16, OBD_BLACK, 1);
  sprintf(msgStr, "V%d.%02d", SW_MAJOR_VERSION, SW_MINOR_VERSION);  
  obdWriteString(&g_obd, 0, 16, 44, msgStr, FONT_12x16, OBD_WHITE, 1);
}


/**
 * Show the Pre-Calibration screen, when the button is pressed during startup, but not yet released
 */
void showScreenPreCalibration() 
{
  sprintf(msgStr, "ESPEED32 v%d.%02d", SW_MAJOR_VERSION, SW_MINOR_VERSION);  //print SW version
  obdWriteString(&g_obd, 0, 8, 0, msgStr, FONT_8x8, OBD_BLACK, 1);
  obdWriteString(&g_obd, 0, (OLED_WIDTH / 2) - 48, 1 * HEIGHT8x8, (char *)"Release button", FONT_8x8, OBD_BLACK, 1);
  obdWriteString(&g_obd, 0, (OLED_WIDTH / 2) - 48, 2 * HEIGHT8x8, (char *)"to calibrate", FONT_8x8, OBD_BLACK, 1);
  obdWriteString(&g_obd, 0, (OLED_WIDTH / 2) - 48, 3 * HEIGHT8x8, (char *)"     OR    ", FONT_8x8, OBD_BLACK, 1);
  obdWriteString(&g_obd, 0, (OLED_WIDTH / 2) - 48, 4 * HEIGHT8x8, (char *)"remove power", FONT_8x8, OBD_BLACK, 1);
  obdWriteString(&g_obd, 0, (OLED_WIDTH / 2) - 48, 5 * HEIGHT8x8, (char *)"  to exit  ", FONT_8x8, OBD_BLACK, 1);
}


/**
 * Show the screen indicating that the stored variables are not present in the EEPROM
 */
void showScreenNoEEPROM() 
{
  sprintf(msgStr, "ESPEED32 v%d.%02d", SW_MAJOR_VERSION, SW_MINOR_VERSION);  //print SW version
  obdWriteString(&g_obd, 0, 0, 0, msgStr, FONT_8x8, OBD_WHITE, 1);
  obdWriteString(&g_obd, 0, (OLED_WIDTH / 2) - 64, 3 * HEIGHT8x8, (char *)"EEPROM NOT init!", FONT_8x8, OBD_BLACK, 1);
  obdWriteString(&g_obd, 0, (OLED_WIDTH / 2) - 48, 5 * HEIGHT8x8, (char *)"Press button", FONT_8x8, OBD_BLACK, 1);
  obdWriteString(&g_obd, 0, (OLED_WIDTH / 2) - 48, 6 * HEIGHT8x8, (char *)"to calibrate", FONT_8x8, OBD_BLACK, 1);
}


/**
 * Show the calibration screen. It displays the current trigger raw value, as well as the max and min encountered values.
 * 
 * @param adcRaw The raw trigger value read from the ADC
 */
void showScreenCalibration(int16_t adcRaw)
{
  sprintf(msgStr, "CALIBRATION");
  obdWriteString(&g_obd, 0, (OLED_WIDTH - 66) / 2, 0, msgStr, FONT_6x8, OBD_WHITE, 1);

  sprintf(msgStr, "press/releas throttle");
  obdWriteString(&g_obd, 0, 0, 8, msgStr, FONT_6x8, OBD_BLACK, 1);

  sprintf(msgStr, "Raw throttle %4d  ", adcRaw);
  obdWriteString(&g_obd, 0, 0, 24, msgStr, FONT_6x8, OBD_BLACK, 1);

  sprintf(msgStr, "Min throttle %4d   ", g_storedVar.minTrigger_raw);
  obdWriteString(&g_obd, 0, 0, 32, msgStr, FONT_6x8, OBD_BLACK, 1);

  sprintf(msgStr, "Max throttle %4d   ", g_storedVar.maxTrigger_raw);
  obdWriteString(&g_obd, 0, 0, 40, msgStr, FONT_6x8, OBD_BLACK, 1);

  sprintf(msgStr, " push when done ");
  obdWriteString(&g_obd, 0, 0, 56, msgStr, FONT_6x8, OBD_BLACK, 1);
}
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

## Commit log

2025-01-16 first commit after cleanup
    [HandleBotV29.3mf, HandleTopV29.3mf, Rounding2sides.3mf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]
2025-10-03 Added Schematic, Gerber, BOM, Altium Project
    [BOM_ESPEED32_V3_0_JLCPCB_only.xlsx, BOM_ESPEED32_V3_0_complete.xlsx, Pick Place for ESPEED32_V3_0_JLC.xlsx]
2025-10-03 Rename Pick Place for ESPEED32_V3_0_JLC.xlsx to PCB-Schematic/Pick Place for ESPEED32_V3_0_JLC.xlsx
    [Pick Place for ESPEED32_V3_0_JLC.xlsx]
2025-11-10 Update README.md
    update mag sensor description
2026-09-14 added also mechanical BOM, bearings, springs,screws and so on
